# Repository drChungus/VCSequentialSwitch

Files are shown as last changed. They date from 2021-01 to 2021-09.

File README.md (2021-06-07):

# Coupled Sequential Switch
#### Double the switches, double the fun!

The Coupled Sequential Switch (CSS) provides two related sequential switches with four steps.
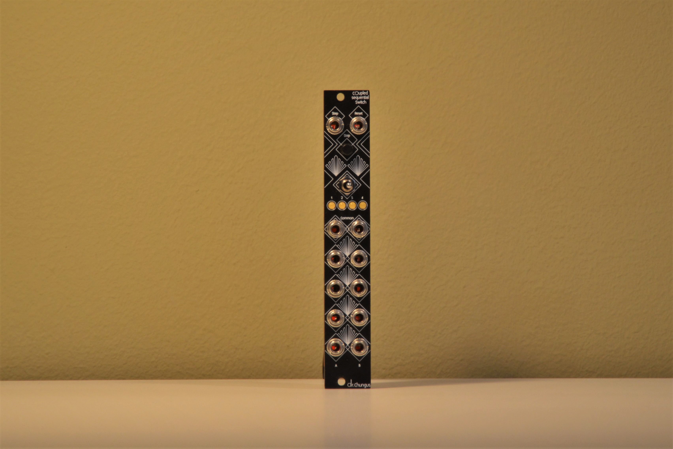
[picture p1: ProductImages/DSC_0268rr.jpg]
The Coupled Sequential Switch


### Specification:
Width:&nbsp;**4 HP**
Depth:&nbsp;**30 mm**
+12V : **5 mA**
-12V: **0 mA**
5V: **0 mA**

A sequential switch is a device to route your signals to different places. The routing can be controlled with a clock signal or a button on the front panel. A reset input is also available to set the switch to its initial routing. This module combines two switches in a small footprint. The signal paths of the two switches are independent, but their state will always be the same. They can be advanced and reset with the same clock signal resulting in a coupled behavior. 
As both switches are always on the same stage this module is ideal to route dual signals, like stereo audio, CV/Gate pairs, and in general vary two independent signals at the same time. Inputs and outputs for the signal path can be switched up!

For more explanation why a sequential switch might be useful in your rack see [mylarmelodies' video](https://www.youtube.com/watch?v=QbxaWluHXEU) on the topic!

##### Inputs:
- Step
- Reset

##### Bipolar:
- 1x I/O
- 4x O/I

##### UI:
- 4x LEDs to indicate the current stage
- Button to advance stage
- Switch to define the number of stages (4, 3 or 2)

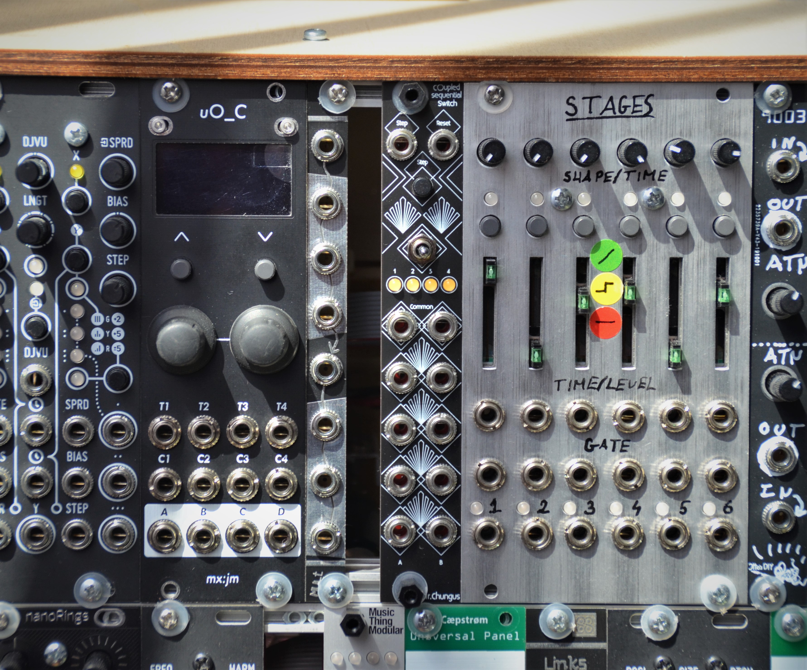
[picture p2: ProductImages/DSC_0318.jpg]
The Coupled Sequential Switch with Friends


NOTE: there might be some reported issues with the current state of the module. Always see [Issues](https://github.com/drChungus/VCSequentialSwitch/issues) reported!

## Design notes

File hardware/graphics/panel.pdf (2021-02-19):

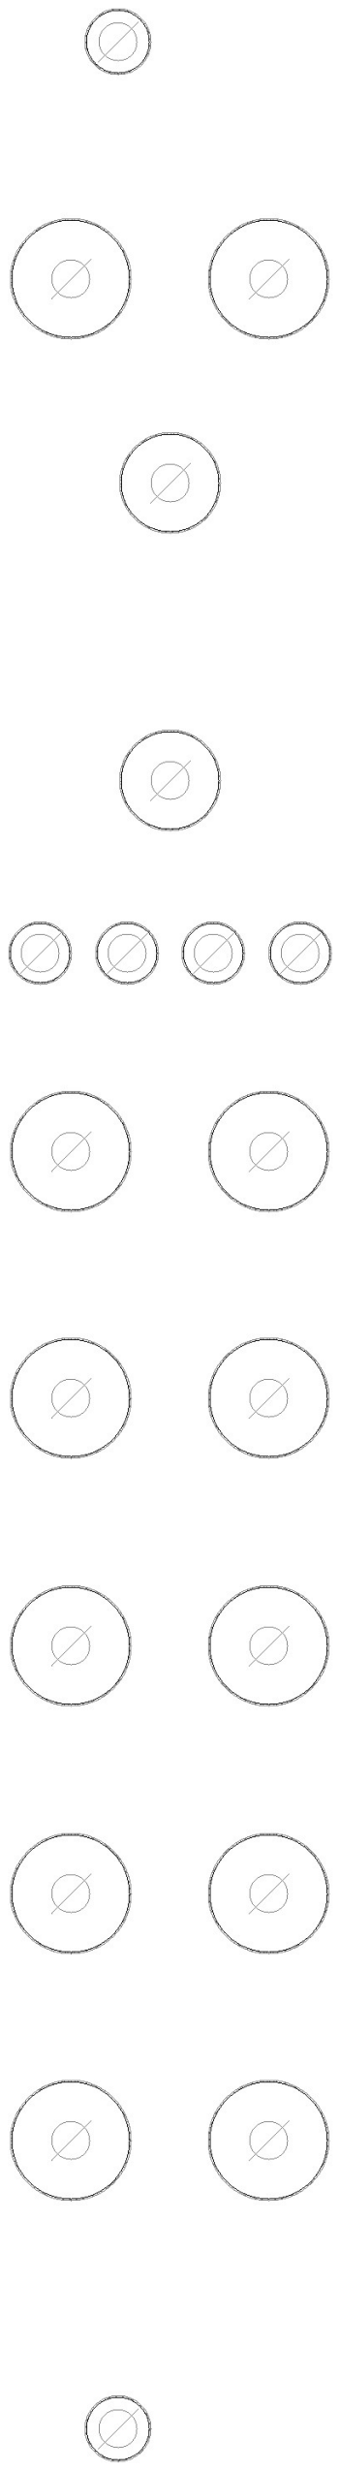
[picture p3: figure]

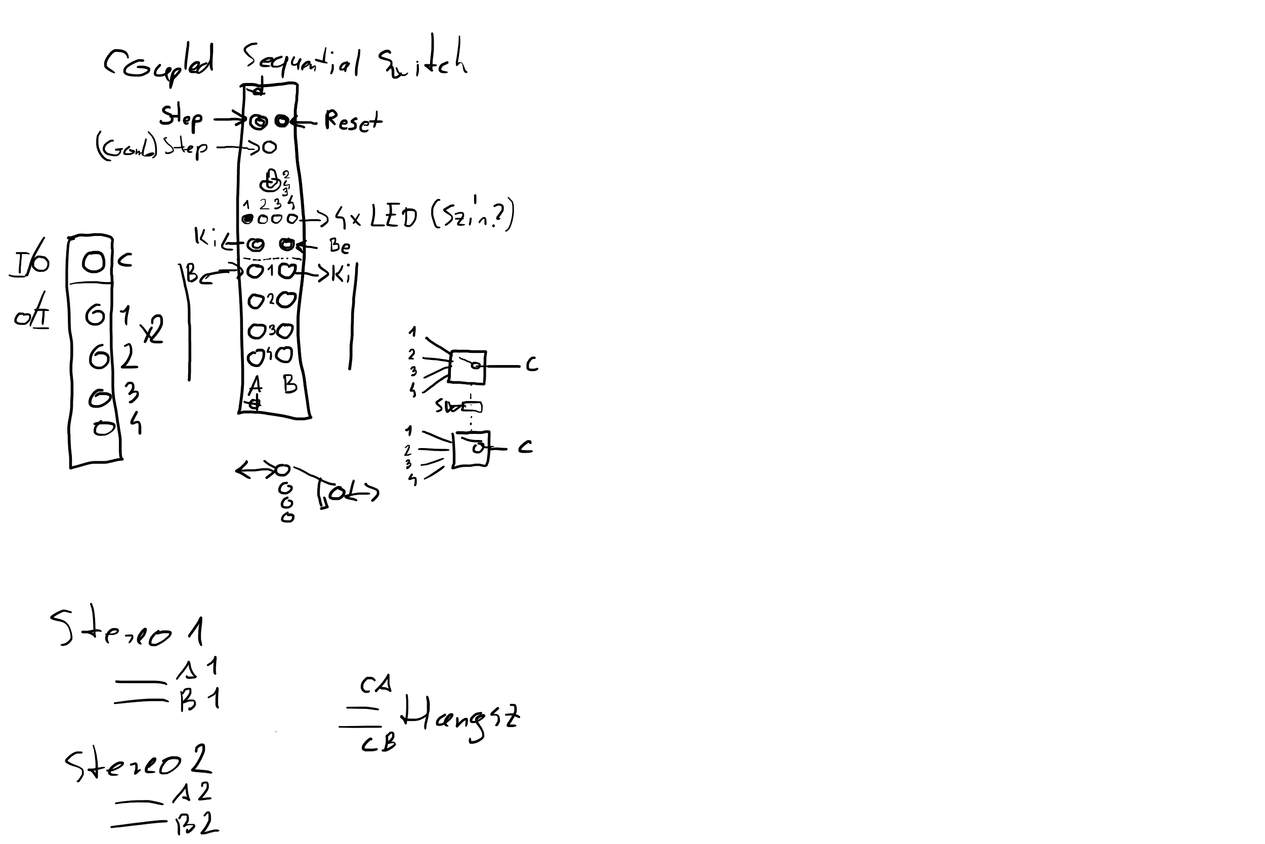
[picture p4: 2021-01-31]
hardware/graphics/exp.png

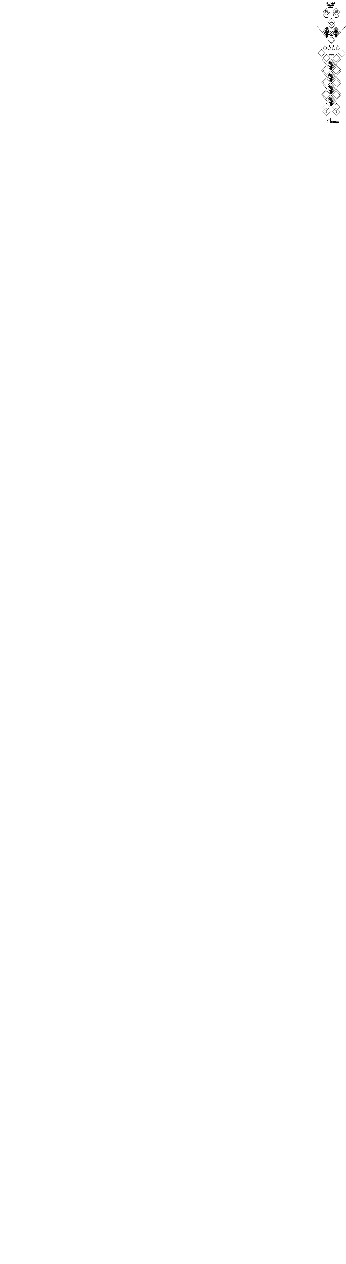
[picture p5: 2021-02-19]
hardware/graphics/Tomi_artdeco8.bmp

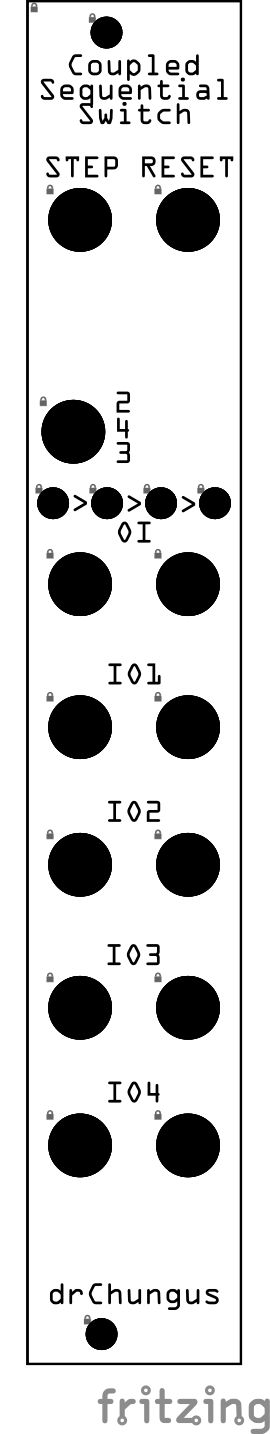
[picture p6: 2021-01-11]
hardware/graphics/panel_pcb1.png

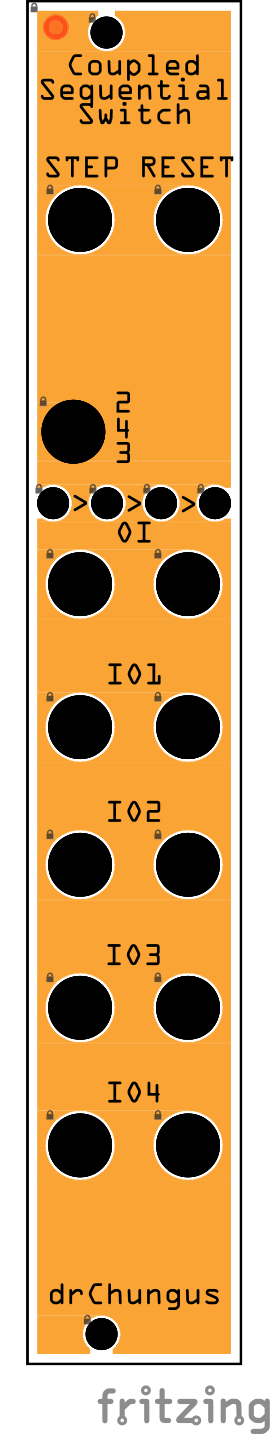
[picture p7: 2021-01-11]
hardware/graphics/panel_pcb.png

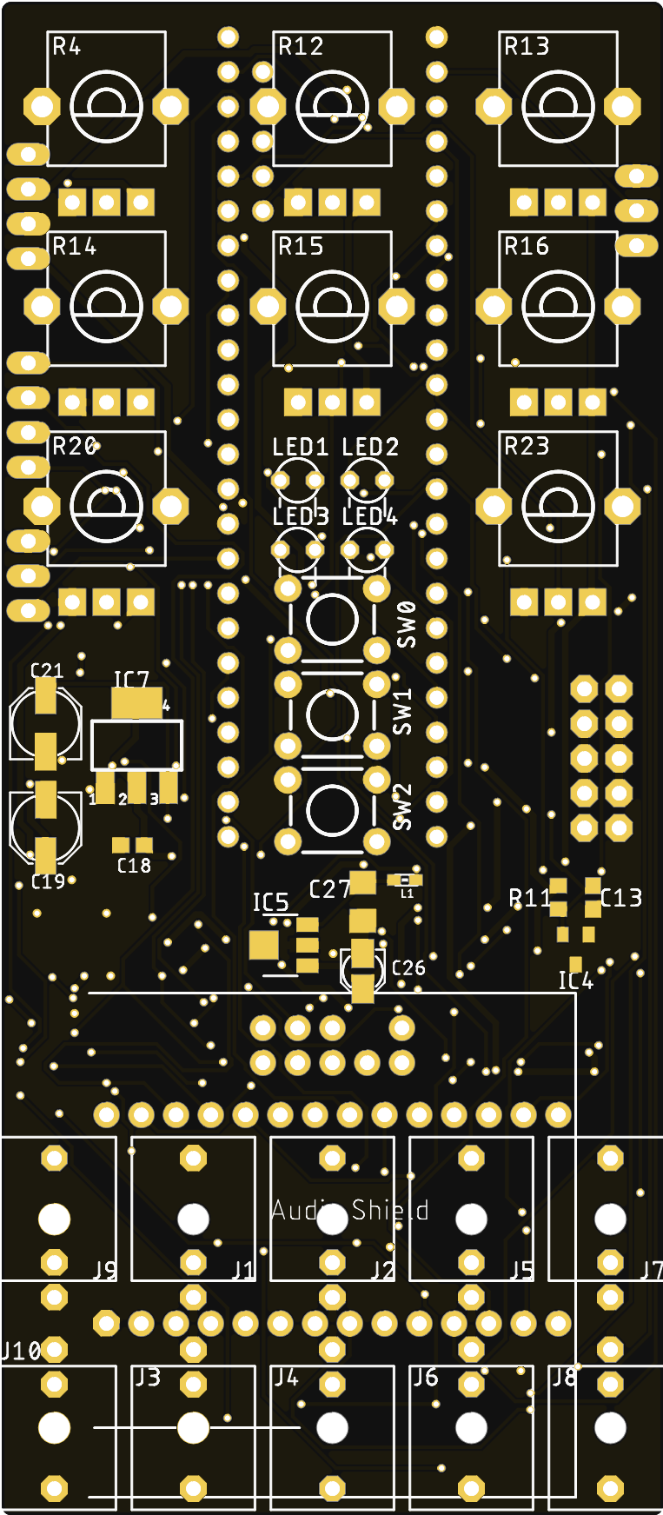
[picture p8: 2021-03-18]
resources/tinrsTools/QuickRender/FinalAfterSilk.png

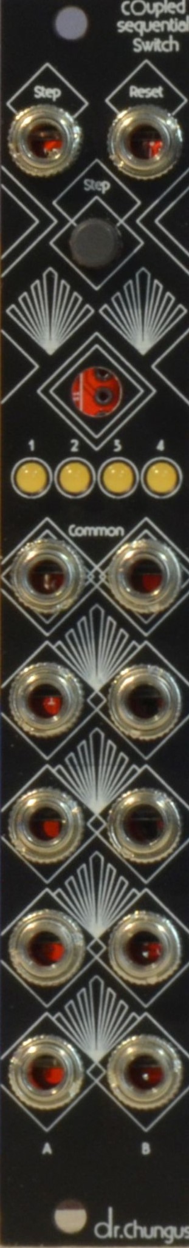
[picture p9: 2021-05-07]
ProductImages/DSC_0185MC.jpg

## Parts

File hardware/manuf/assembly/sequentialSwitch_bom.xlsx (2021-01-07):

Comment | Designator | Footprint | LCSC Part #（optional）
47uF | C1, C2 |  | C117835
10nF | C3, C4, C7, C8, C9 | 0603_C | C57112
1N5819WS | D1, D2 | sod-323 | C440261
1N4148 | D3, D4, D5, D6 | sod523 | C414017
4017 | IC1 | so-16 | C484717
DG5412 | IC2, IC3 | SSOP-16 | C209546
2N3904 | Q1, Q2, Q3, Q4 | SOT-23 | C18536
47k | R1, R4, R6, R8 | 0402_R | C25792
10k | R2, R3, R5, R7 | 0402_R | C25744
1k | R9, R10, R11, R12, R13, R16, R17, R18, R19, R20, R21 | 0402_R | C11702

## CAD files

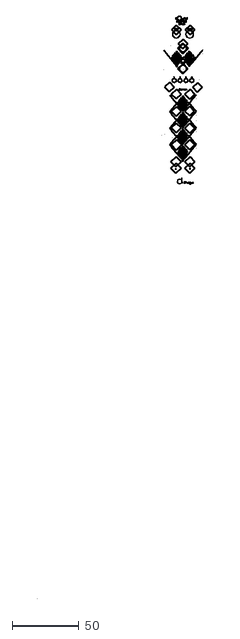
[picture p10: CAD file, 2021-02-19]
hardware/graphics/Tomi_artdeco8.dxf
124.3 x 436.9

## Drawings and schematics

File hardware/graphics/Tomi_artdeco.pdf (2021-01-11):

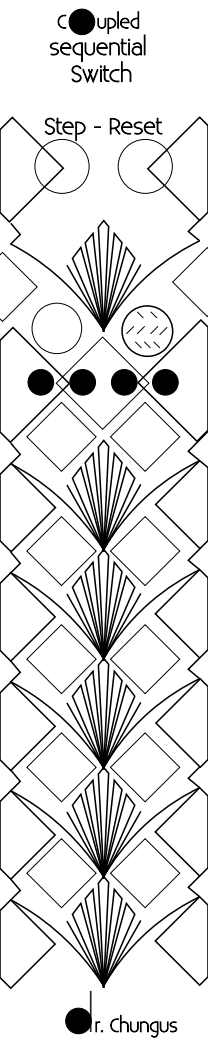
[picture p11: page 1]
C o upled sequential Switch; Step - Reset; lr. Chungus

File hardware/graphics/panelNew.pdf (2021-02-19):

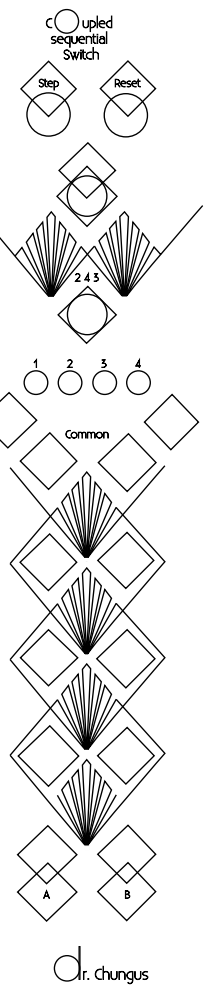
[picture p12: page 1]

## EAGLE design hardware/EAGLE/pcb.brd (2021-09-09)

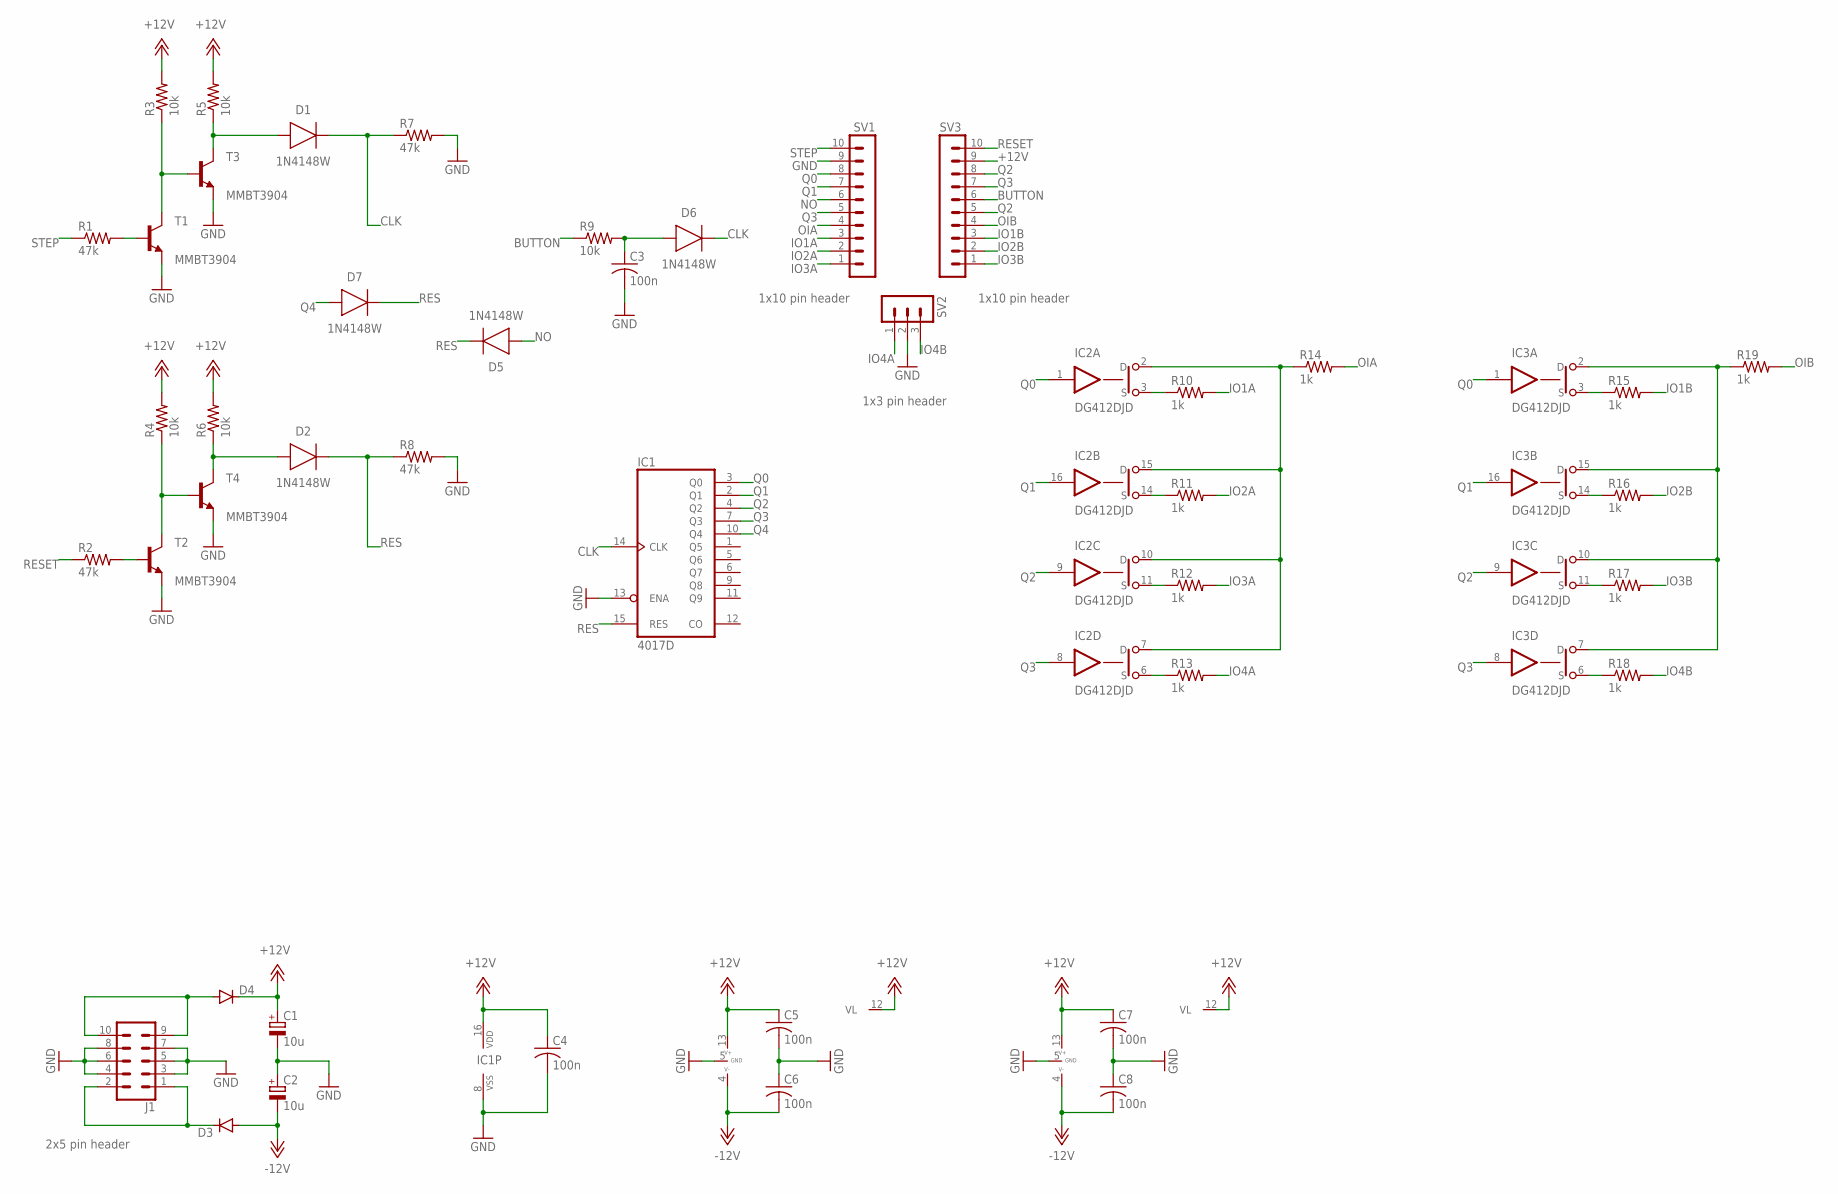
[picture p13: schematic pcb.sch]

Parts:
C1, C2: 10u; 153CLV-0605
C3, C4, C5, C6, C7, C8: 100n; C0603
D1, D2, D5, D6, D7: 1N4148W; SOD3715X135
D3, D4: DIODE-SOD123; SOD123
IC1: 4017D; SO16
IC2, IC3: DG412DJD; SO16
J1: 2x5 pin header; 2X5-SHROUDED
R1, R2, R7, R8: 47k; R0603
R3, R4, R5, R6, R9: 10k; R0603
R10, R11, R12, R13, R14, R15, R16, R17, R18, R19: 1k; R0603
SV1, SV3: 1x10 pin header; MA10-1
SV2: 1x3 pin header; MA03-1
T1, T2, T3, T4: MMBT3904; SOT23-BEC

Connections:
+12V: C1.+, C4.1, C5.1, C7.1, D4.C, IC1.16 (VDD), IC2.12 (VL), IC2.13 (V+), IC3.12 (VL), IC3.13 (V+), R3.2, R4.2, R5.2, R6.2, SV3.9
-12V: C2.-, C6.2, C8.2, D3.A, IC2.4 (V-), IC3.4 (V-)
BUTTON: R9.1, SV3.6
CLK: D1.1 (C), D6.1 (C), IC1.14 (CLK), R7.1
GND: C1.-, C2.+, C3.2, C4.2, C5.2, C6.1, C7.2, C8.1, IC1.8 (VSS), IC1.13 (ENA), IC2.5 (GND), IC3.5 (GND), J1.3, J1.4, J1.5, J1.6, J1.7, J1.8, R7.2, R8.2, SV1.9, SV2.2, T1.E, T2.E, T3.E, T4.E
IO1A: R10.2, SV1.3
IO1B: R15.2, SV3.3
IO2A: R11.2, SV1.2
IO2B: R16.2, SV3.2
IO3A: R12.2, SV1.1
IO3B: R17.2, SV3.1
IO4A: R13.2, SV2.1
IO4B: R18.2, SV2.3
unnamed: D4.A, J1.9, J1.10
unnamed: D3.C, J1.1, J1.2
unnamed: IC2.2 (D), IC2.7 (D), IC2.10 (D), IC2.15 (D), R14.1
unnamed: IC2.3 (S), R10.1
unnamed: IC3.2 (D), IC3.7 (D), IC3.10 (D), IC3.15 (D), R19.1
unnamed: IC2.14 (S), R11.1
unnamed: IC2.11 (S), R12.1
unnamed: IC2.6 (S), R13.1
unnamed: IC3.3 (S), R15.1
unnamed: IC3.14 (S), R16.1
unnamed: IC3.11 (S), R17.1
unnamed: IC3.6 (S), R18.1
unnamed: C3.1, D6.2 (A), R9.2
unnamed: R1.2, T1.B
unnamed: R3.1, T1.C, T3.B
unnamed: D1.2 (A), R5.1, T3.C
unnamed: R2.2, T2.B
unnamed: R4.1, T2.C, T4.B
unnamed: D2.2 (A), R6.1, T4.C
NO: D5.2 (A), SV1.6
OIA: R14.2, SV1.4
OIB: R19.2, SV3.4
Q0: IC1.3 (Q0), IC2.1 (IN), IC3.1 (IN), SV1.8
Q1: IC1.2 (Q1), IC2.16 (IN), IC3.16 (IN), SV1.7
Q2: IC1.4 (Q2), IC2.9 (IN), IC3.9 (IN), SV3.5, SV3.8
Q3: IC1.7 (Q3), IC2.8 (IN), IC3.8 (IN), SV1.5, SV3.7
Q4: D7.2 (A), IC1.10 (Q4)
RES: D2.1 (C), D5.1 (C), D7.1 (C), IC1.15 (RES), R8.1
RESET: R2.1, SV3.10
STEP: R1.1, SV1.10

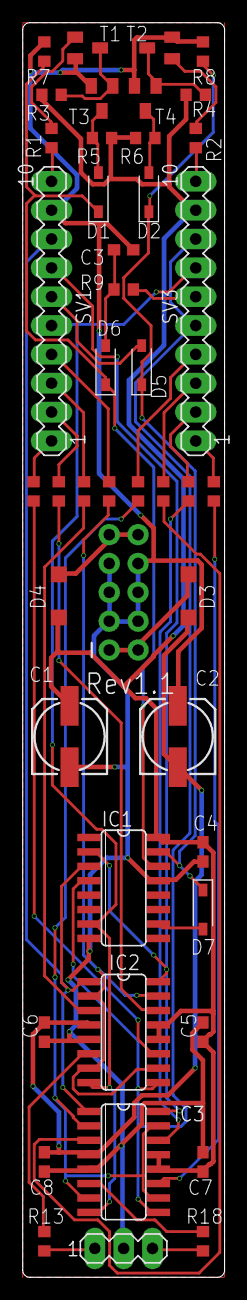
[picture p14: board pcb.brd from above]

Board: 2 copper layers, 17.8 x 110.5 mm, 46 parts (1 on the bottom side), 43 nets.

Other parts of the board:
U$1: EURO_PCB_4HP

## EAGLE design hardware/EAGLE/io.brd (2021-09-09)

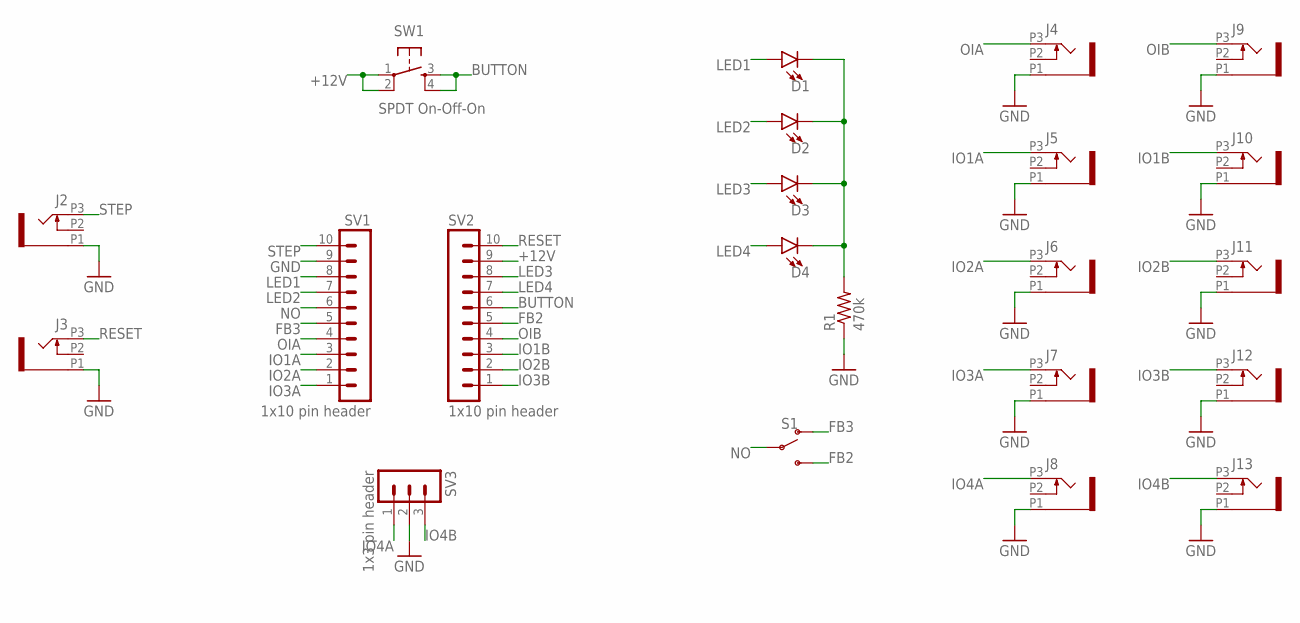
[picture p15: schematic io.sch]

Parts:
D1, D2, D3, D4: LED3MM; LED_3MM
J2, J3, J4, J5, J6, J7, J8, J9, J10, J11, J12, J13: PJ301_THONKICONN6; WQP_PJ_301M6
R1: 470k; R0603
S1: SWITCH-SPDT-PTH-11.6X4.0MM-SHORT_LEADS; SWITCH_SPDT_PTH_11.6X4.0MM
SV1, SV2: 1x10 pin header; MA10-1
SV3: 1x3 pin header; MA03-1
SW1: SPDT On-Off-On; TACTILE-PTH

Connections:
+12V: SV2.9, SW1.1, SW1.2
BUTTON: SV2.6, SW1.3, SW1.4
FB2: S1.3 (S), SV2.5
FB3: S1.1 (O), SV1.5
GND: J2.P1 (1), J3.P1 (1), J4.P1 (1), J5.P1 (1), J6.P1 (1), J7.P1 (1), J8.P1 (1), J9.P1 (1), J10.P1 (1), J11.P1 (1), J12.P1 (1), J13.P1 (1), R1.1, SV1.9, SV3.2
IO1A: J5.P3 (3), SV1.3
IO1B: J10.P3 (3), SV2.3
IO2A: J6.P3 (3), SV1.2
IO2B: J11.P3 (3), SV2.2
IO3A: J7.P3 (3), SV1.1
IO3B: J12.P3 (3), SV2.1
IO4A: J8.P3 (3), SV3.1
IO4B: J13.P3 (3), SV3.3
LED1: D1.A, SV1.8
LED2: D2.A, SV1.7
LED3: D3.A, SV2.8
LED4: D4.A, SV2.7
unnamed: D1.K (C), D2.K (C), D3.K (C), D4.K (C), R1.2
NO: S1.2, SV1.6
OIA: J4.P3 (3), SV1.4
OIB: J9.P3 (3), SV2.4
RESET: J3.P3 (3), SV2.10
STEP: J2.P3 (3), SV1.10

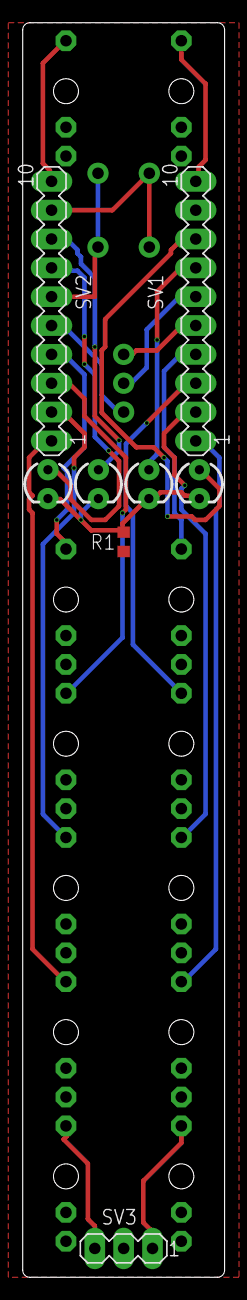
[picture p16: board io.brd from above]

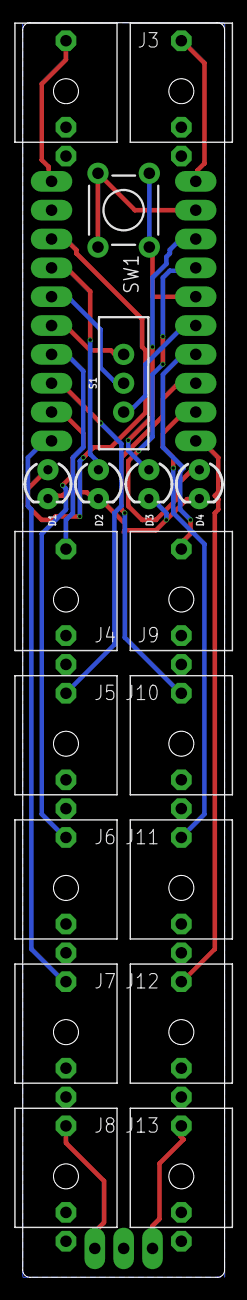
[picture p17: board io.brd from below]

Board: 2 copper layers, 17.8 x 110.5 mm, 23 parts (18 on the bottom side), 23 nets.

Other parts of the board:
U$1: EURO_PCB_4HP

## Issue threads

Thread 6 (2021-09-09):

Incorrect BOM?

KeLaiFu, 2021-09-09:
I just had these boards made up and grabbed the BOM from various stores while I was waiting for delivery. However the IC listed for IC1 and 2, accoridng to the BOM is a DG5412, which is a different chip to the one thats expected on the board. I made a new BOM from the eagle file and it lists a DG412DJC1 for that reference, which looks like the correct china according to the footprint.

drChungus, 2021-09-09:
Hey @KeLaiFu ,

You are correct, I recon replacing the DG412 with a more modern alternative, but the actual prototypes I made use the DG412. Regarding functionality, the DG5412 is a direct replacement of the DG412, but does not seem to be available in an SOIC package, which is used on the final PCB. Thus the BOM should refer to the DG412, also to be consistent with he EAGLE file.

Thanks for the heads-up!

Closed 2021-09-09.

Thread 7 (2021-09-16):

Still large differences between published BOM and eagle created BOM

KeLaiFu, 2021-09-16:
As per title, the BOM created from eagle is very different to the BOM published in the repo. Can you clarify if I should just follow the BOM from Eagle, I would assume this one to be correct but I am not experienced in eagle to be sure.

drChungus, 2021-09-16:
Hey,
the most recent design is made in EAGLE and the only BOMs generated are for the archived (aka deprecated) version. Feel free to generate the BOM from EAGLE.
The parts needed are the passives, the 4017, the DG412 and the 3904s. Use the parts listed in the EAGLE file and make sure you pick the ones with the proper footprint.

Closed 2021-09-16.

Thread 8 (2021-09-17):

Brighter LEDs?

KeLaiFu, 2021-09-17:
Ok so this should be my last 'issue'!

I've successfully built the module and it works great, so thanks for sharing this great project, buuuut, is there a way to increase the brightness the LEDs? Currently my lights are easily visible, but they would certainly benefit to being a lot brighter. I looked around the PCB and the voltage for the LEDS seems to be coming directly from a chip leg, although I could well be mistaken.

drChungus, 2021-09-24:
Hey there @KeLaiFu!

You can adjust the brightness of the LEDs by switching the value of R1 on the IO board. If you want to have your lights brighter, simply replace the resistor to a lower value, and vice-versa. I recommend you have a look at the datasheet of the LEDs you use, so you can have a reference on what current you want to drive them with.
Note that R1 is the only resistor on the IO PCB. As practically only one LED is expected to be on at any given time, the current limiting resistor is a common one for all the stages.
Fun fact: I built the modules with warm white LEDs, hence the higher resistance for the current limiting.

Closed 2021-09-24.

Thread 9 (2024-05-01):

Resistor footprint clarification

extremenerble, 2024-05-01:
Hello, in your BOM the resistors are listed as 0402 size, but the footprints in the Eagle file Properties say 0603. Could you clarify the correct size?

Many thanks!

extremenerble, 2024-05-02:
Ok, I think I gleaned from a resolved issue that the Eagle BOM is the correct one and the resistors are in fact 0603.

Closed 2024-05-02.

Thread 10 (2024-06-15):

DG412 version substitution

extremenerble, 2024-06-15:
Hello, it seems there's a [<$2 version](https://www.mouser.com/ProductDetail/Vishay-Semiconductors/DG412DQ-T1-E3?qs=avFSO%252B7Rp3jHOzwqyNEU6w%3D%3D) of the DG412 compared to the [$7 version](https://www.mouser.com/ProductDetail/Analog-Devices/ADG5412BRUZ-REEL7?qs=BpaRKvA4VqEmn7QB78QemQ%3D%3D) listed in the Eagle BOM. Is there any harm in using the cheaper one?

The only real differences are a lower minimum supply voltage and these:

Spec | cheaper part  | original part
Off Time - Max: | 160 ns | 145 ns
On Resistance - Max: | 45 Ohms | 11 Ohms
On Time - Max: | 240 ns | 202 ns

Thanks in advance.

drChungus, 2024-06-19:
Hey there!
By looking at the Datasheet I believe the substitution would work. As you noted, the biggest difference is the increased resistance. This would not make a noticeable difference when routing triggers/gates or audio signals, bit the increased voltage drop would affect control voltage, making V/Oct signals be more out of tune. In general I would recommend quantizing such signal routed through the switch anyway, but the replacement part would make this imperfection more pronounced.
Note that no testing was or could be performed by myself with the replacement part you mentioned, but I would be thrilled to hear back from you if you go ahead and build the unit with the cheaper part.

extremenerble, 2024-06-23:
thanks for the feedback! i may try one with the cheaper chips and one with the correct chips. i think having v/Oct may be key for a lot of patches.

cheers

Closed 2024-06-23.

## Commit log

2021-01-04 Initial Commit
    Uploading schematic and .fzz file.
    Circuitry is verified (more or less). Started working on footprints.
    [SequencialSwitch.fzz]
2021-01-04 Update SequencialSwitch.fzz
    Updated footprints.
    [SequencialSwitch.fzz]
2021-01-04 Update SequencialSwitch.fzz
    arranged jack positions - in theory, needs verification
    [SequencialSwitch.fzz]
2021-01-04 Update SequencialSwitch.fzz
    Top and Bottom layer adjustments
    [SequencialSwitch.fzz]
2021-01-04 Update SequencialSwitch.fzz
    Top and Bottom switched, external parts locked
    [SequencialSwitch.fzz]
2021-01-05 Messing with footprint
    [SequencialSwitch.fzz]
2021-01-05 Update SequencialSwitch.fzz
    Locked FP related parts
    [SequencialSwitch.fzz]
2021-01-05 Update SequencialSwitch.fzz
    added layout, added holes
    [SequencialSwitch.fzz]
2021-01-05 Layout started
    And panel added
    [SequencialSwitch.fzz, panel.fzz]
2021-01-05 Update SequencialSwitch.fzz
    added new part numbers and footprints :(
    [SequencialSwitch.fzz]
2021-01-05 Removed Reset Button, added Reset Switch
    Also reorganized layout
    [SequencialSwitch.fzz, panel.fzz]
2021-01-05 Started Routing
    [SequencialSwitch.fzz, panel.fzz]
2021-01-06 Increased PCB size
    20mm is the minimal required pcb size, thus it was enlarged. Also continued routing.
    [SequencialSwitch.fzz, panel.fzz]
2021-01-06 First Gerber
    Generated first gerber file
    [SequencialSwitch.fzz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]
2021-01-06 Update SequencialSwitch.fzz
    removed step button
    [SequencialSwitch.fzz]
2021-01-06 Routing..
    Routing Baby!
    [SequencialSwitch.fzz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]
2021-01-06 Update SequencialSwitch.fzz
    routing almost done
    [SequencialSwitch.fzz]
2021-01-06 Update SequencialSwitch.fzz
    super Fine!
    [SequencialSwitch.fzz]
2021-01-07 Routing Completed
    [SequencialSwitch.fzz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]
2021-01-07 Panel Outline Done
    [SequencialSwitch.fzz, panel.fzz]
2021-01-07 Panel design added
    [panel.fzz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]
2021-01-07 Update panel.fzz
    Added mounting holes and text
    [panel.fzz]
2021-01-07 CAM prep
    Created manufacturing files. Jlc has some troubles understanding the pnp
    [SequencialSwitch.fzz, alt_pnp.xlsx, panel.fzz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]
2021-01-08 DESIGN FREEZE
    Successfully converted pnp file, after final inspection should be ready for manufacturing
    [SequencialSwitch_dummyPNP.fzz, alt_pnp.xlsx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]
2021-01-08 Locked PCB
    And fixed some minor layout issues. PCB is ready.
    [SequencialSwitch.fzz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]
2021-01-08 wORKING ON pANEL dESIGN
    [panel.fzz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]
2021-01-11 Added 1st iteration art
    [SequencialSwitch.fzz, panel.fzz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]
2021-01-27 Started EAGLE version of design
    Using components already in personal stash
    [pcb.brd, pcb.sch]
2021-01-27 Eagle design finished
    [io.brd, io.sch]
2021-01-27 FINALIZED PCBs
    [io.brd, io.sch, panel.brd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]
2021-01-27 gerbers with some errors
    gnd pane on pcb
2021-01-27 Submitted for Artist
    and quick fixed layer errors
    [io.brd, pcb.brd]
2021-01-28 Added text and logo
    [io.brd, pcb.brd, pcb.sch]
2021-01-28 6mm Switch hole
    6
    [panel.brd]
2021-01-31 Added BOM
    And buffer caps, and refined design
    [BOM.xlsx, SequencialSwitch.fzz, SequencialSwitch_dummyPNP.fzz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]
2021-01-31 Updated BOM with personal stash info
    [BOM.xlsx]
2021-02-19 Art
    Added art
    [Tomi_artdeco8.dxf, panel.brd, panel.sch]
2021-02-22 finalized Panel
    ready for production
    [panel.brd]
2021-02-23 panel
    noPanel
    [gerber_job.gbrjob, io.GBL, io.GBO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]
2021-05-06 Looking at documentation for build
    [pcb.sch]
2021-06-07 Transistor footprint fixed
    [pcb.brd, pcb.sch]
2021-06-22 Fixed some layout issues
    [pcb.brd, pcb.sch]
2021-06-22 Added smd 4017 footprint
    [pcb.brd, pcb.sch]
2021-07-28 Deleted Temp files
    [BOM.xlsx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]
2021-09-09 Update sequentialSwitch_bom.xlsx
    Fixed a wrong reference to the DG412 in the manufacturing (PNP) file.
    [sequentialSwitch_bom.xlsx]

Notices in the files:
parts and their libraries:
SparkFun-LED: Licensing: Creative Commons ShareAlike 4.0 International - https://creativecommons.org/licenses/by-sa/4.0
